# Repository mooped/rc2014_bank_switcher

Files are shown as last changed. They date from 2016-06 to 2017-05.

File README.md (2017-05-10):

# RC2014 Bank Switcher
Implements a minimal bank switcher to swap the RC2014 boot ROM for 32kB of RAM with 1x 74HCT00, 1x 74LS32, and 1x 74HCT04.

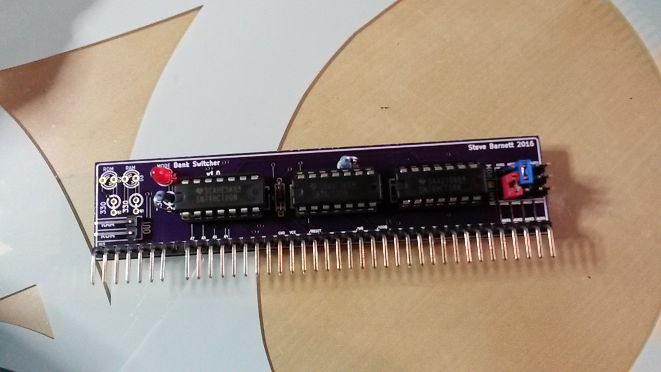
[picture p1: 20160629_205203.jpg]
Assembled Board


Designed to work with one standard RC2014 ROM module and two standard RC2014 RAM modules.

One RAM module and the bank switcher are installed in any slot in the centre of the backplane (slots 3-8). The ROM and the second RAM module need their A15 signal replaced with output from the bank switcher. This is most easily achieved through the jumpers on the RC2014 backplane between slots 2 and 3 and slots 6 and 7.

In my setup the extra RAM is installed in slot 2 and the ROM installed in slot 7, any RC2014 board that does not require A15 (eg. the serial board, IO board, clock board) can be installed in slots 1 and 8. Jumpers A14 to A0 and D0 to D7 are bridged on both sides of the backplane. Pin headers are installed in Tx, Rx and the four auxilliary bus lines. The replacement A15 signals for the ROM and the extra RAM are brought out to Aux 1 and Aux 2 by setting jumpers on the bank switcher board. Aux 1 is then connected to A15 on the slot 2 side of the left A15 jumper. Aux 2 is conneccted to A15 on the slot 7 side of the right A15 jumper.

The ROM and RAM A15 signals are also brought out to a header at the A15 end of the bank switcher board to simplify alternative setups.

ROM is mapped as usual (0x0000 to 0x1fff) on reset. Any write to IO address 0xf0 to 0xff will disable the ROM and enable a standard RC2014 32kB RAM module (0x000 to 0x7fff). It is not possible to switch the ROM back in except on a reset.

The gerbers in v1.0 have been tested and work correctly. Later versions have not been built or tested. There is a minor error in v1.0: the hole for pin A8 of the RC2014 bus header is too small for a standard header. This signal is not used so the problem is resolved by simply removing the pin from the header.

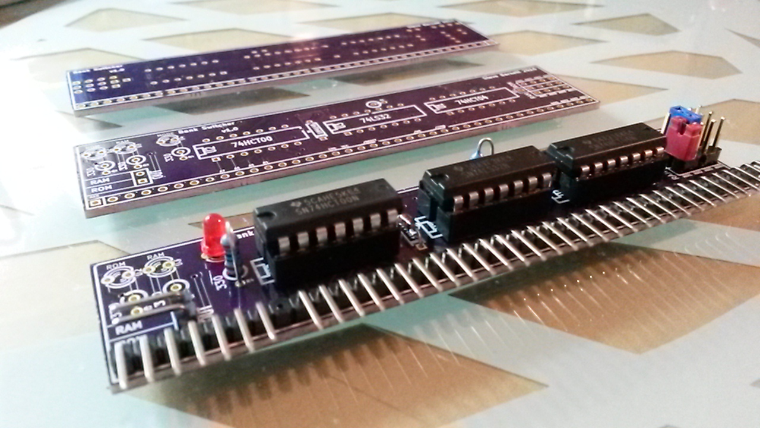
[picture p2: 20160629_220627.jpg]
Boards


v1.0 - Initial revision.

v1.1 - Enlarged A8 of the RC2014 bus header. Enlarged holes for P3 (auxilliary A15 output header).

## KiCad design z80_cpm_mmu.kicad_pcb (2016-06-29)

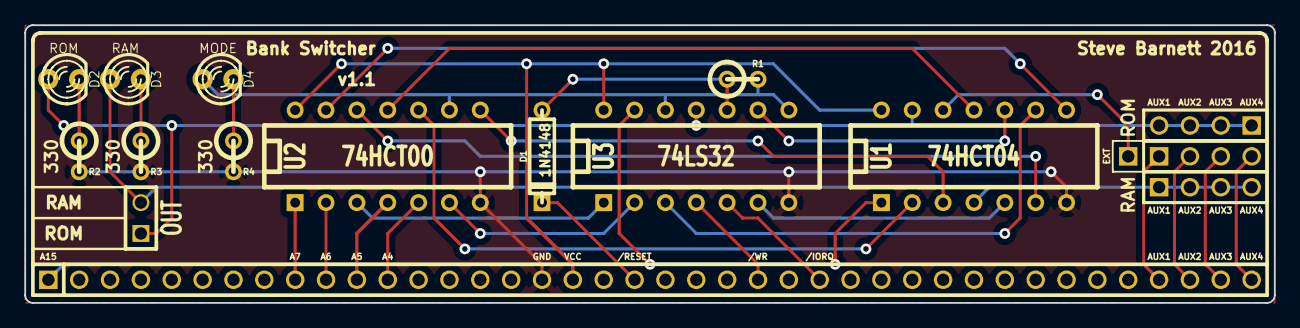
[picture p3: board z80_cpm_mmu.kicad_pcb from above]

Board: 2 copper layers, 102.9 x 22.9 mm, 17 parts (0 on the bottom side), 32 nets.

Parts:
D1: 1N4148; D3
D2: ROM; LED-3MM
D3: RAM; LED-3MM
D4: MODE; LED-3MM
P1: BUS; SIL-40
P2: ROM; PIN_ARRAY_4x1
P3: OUT; SIL-2
P4: RAM; PIN_ARRAY_4x1
P5: AUX; PIN_ARRAY_4x1
P6: EXT; PIN_ARRAY_1
R1: 1K2; R1
R2, R3, R4: 330; R1
U1: 74HCT04; DIP-14__300
U2: 74HCT00; DIP-14__300
U3: 74LS32; DIP-14__300

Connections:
//IORQ: P1.26, U3.5
//WR: P1.24, U3.4
/A4: P1.12, U2.5
/A5: P1.11, U2.4
/A6: P1.10, U2.2
/A7: P1.9, U2.1
/A15: P1.1, U1.1, U3.13
/AUX1: P1.37, P5.1
/AUX2: P1.38, P5.2
/AUX3: P1.39, P5.3
/AUX4: P1.40, P5.4
/RAM_A15: D3.1, P3.2, P4.1, P4.2, P4.3, P4.4, U1.4
/RESET: D1.2, P1.20
/ROM_A15: D2.1, P2.1, P2.2, P2.3, P2.4, P3.1, U1.13, U3.11
/mode: D4.1, R1.2, U2.9, U3.8, U3.12
GND: P1.17, R2.2, R3.2, R4.2, U1.7, U2.7, U3.7
unnamed: U1.10, U3.9
unnamed: U1.11, U2.11
unnamed: U1.8, U2.13
unnamed: U1.6, U2.12
unnamed: D1.1, R1.1, U3.10
unnamed: D2.2, R2.1
unnamed: D4.2, R4.1
unnamed: D3.2, R3.1
unnamed: P6.1, U1.12
unnamed: U1.3, U2.8
unnamed: U1.2, U2.10
unnamed: U1.5, U3.6
unnamed: U2.3, U3.1
unnamed: U1.9, U3.3
unnamed: U2.6, U3.2
VCC: P1.18, U1.14, U2.14, U3.14

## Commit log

2016-06-13 Plot v1.0
    [z80_cpm_mmu.kicad_pcb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]
2016-06-13 Rework silk screen on v1.0
    [z80_cpm_mmu-B_Cu.gbl, z80_cpm_mmu-B_Mask.gbs, z80_cpm_mmu-B_SilkS.gbo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]
2016-06-13 Fix IC references to be contiguous
    [z80_cpm_mmu-B_Cu.gbl, z80_cpm_mmu-B_Mask.gbs, z80_cpm_mmu-B_SilkS.gbo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]
2016-06-13 Begin work on v1.1 - fix size of bus pad 8
    [z80_cpm_mmu.kicad_pcb, z80_cpm_mmu.sch]
2016-06-29 Enlarge holes for P3 header
    [z80_cpm_mmu.kicad_pcb]
2017-05-10 Add photos of the board
